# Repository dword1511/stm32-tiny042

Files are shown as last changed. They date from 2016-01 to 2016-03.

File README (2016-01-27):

This project contains a minimalist USB board for STM32F042F6P6. It has PA0-PA7
pins broken out and a LED connected to PA14, and can serve as a highly compact
development board.

My version of the board uses a LP5907 LDO. Other LDOs in SOT23-5 packages
should also work, but you may need to cut the "bypass" pin of your LDO. (LP5907
does not have a bypass pin, so it is grounded.)

The project also contains a blinky example, which may be used as a foundation
for other projects. To build, simply type "make", or read the header of the
Makefile for details. To flash, connect BOOT0 ("BT0") to 3.3V ("3V3") on the
board, plug the board into a USB slot, then type "make flash". Depending system
configuration, you may need to use sudo. See

  http://www.libopencm3.org/wiki/USB_DFU

for details. Having a udev rule in place is highly recommended so you do not
have to run make with root privilege.

Order link on OSH Park:

  https://oshpark.com/shared_projects/WYQE2OGu

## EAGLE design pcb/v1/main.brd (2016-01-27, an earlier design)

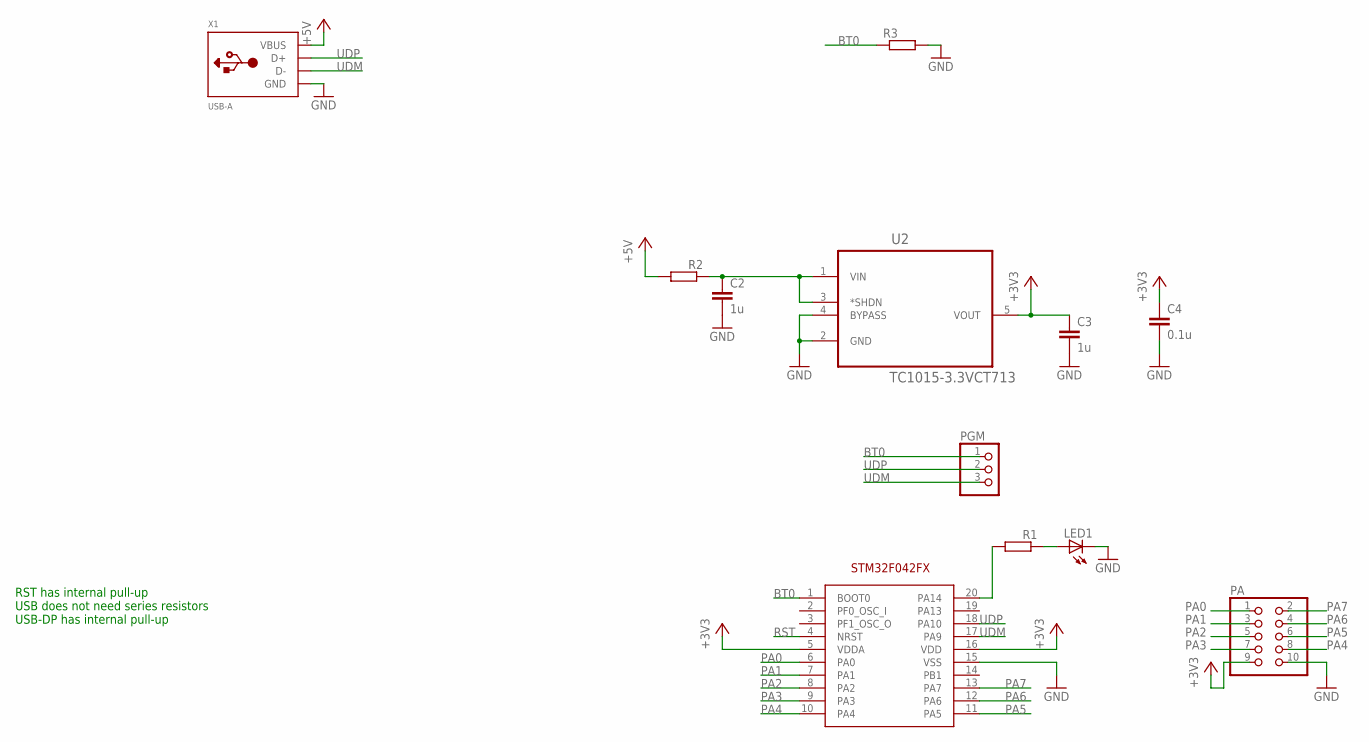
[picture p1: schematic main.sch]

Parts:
C2, C3: 1u; C0805K
C4: 0.1u; C0805K
LED1: LEDCHIPLED_0805; CHIPLED_0805
PA: PINHD-2X5; 2X05
PGM: PINHD-1X3; 1X03
R1, R2, R3: R-EU_R0805; R0805
U1: STM32F042FX; TSSOP20
U2: TC1015-3.3VCT713; SOT95P270X145-5N
X1: USB-A; MOLEX_480371000

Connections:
+3V3: C3.1, C4.1, PA.9, U1.5 (VDDA), U1.16 (VDD), U2.5 (VOUT)
+5V: R2.2, X1.1 (VBUS)
BT0: PGM.1, R3.1, U1.1 (BOOT0)
GND: C2.2, C3.2, C4.2, LED1.C, PA.10, R3.2, U1.15 (VSS), U2.2 (GND), U2.4 (BYPASS), X1.4 (GND)
unnamed: R1.2, U1.20 (PA14)
unnamed: LED1.A, R1.1
unnamed: C2.1, R2.1, U2.1 (VIN), U2.3 (*SHDN)
PA0: PA.1, U1.6 (PA0)
PA1: PA.3, U1.7 (PA1)
PA2: PA.5, U1.8 (PA2)
PA3: PA.7, U1.9 (PA3)
PA4: PA.8, U1.10 (PA4)
PA5: PA.6, U1.11 (PA5)
PA6: PA.4, U1.12 (PA6)
PA7: PA.2, U1.13 (PA7)
RST: U1.4 (NRST)
UDM: PGM.3, U1.17 (PA9), X1.2 (D-)
UDP: PGM.2, U1.18 (PA10), X1.3 (D+)

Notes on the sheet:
RST has internal pull-up USB does not need series resistors USB-DP has internal pull-up

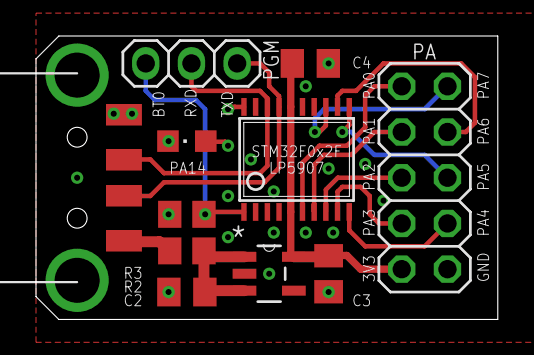
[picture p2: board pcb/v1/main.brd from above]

Board: 2 copper layers, 25.7 x 15.7 mm, 12 parts (1 on the bottom side), 17 nets.

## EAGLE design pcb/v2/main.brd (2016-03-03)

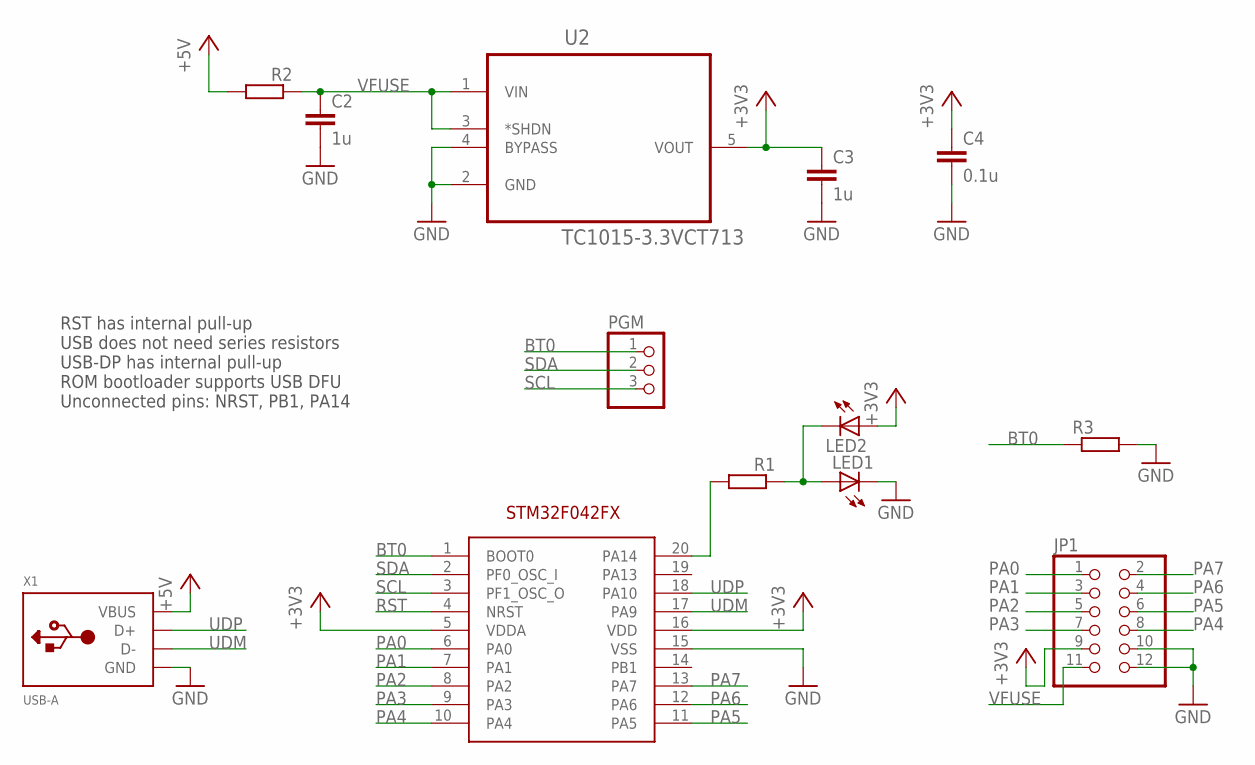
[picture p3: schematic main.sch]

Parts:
C2, C3: 1u; C0805K
C4: 0.1u; C0805K
JP1: PINHD-2X6; 2X06
LED1, LED2: LEDCHIPLED_0805; CHIPLED_0805
PGM: PINHD-1X3; 1X03
R1, R2, R3: R-EU_R0805; R0805
U1: STM32F042FX; TSSOP20
U2: TC1015-3.3VCT713; SOT95P270X145-5N
X1: USB-A; MOLEX_480371000

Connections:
+3V3: C3.1, C4.1, JP1.9, LED2.A, U1.5 (VDDA), U1.16 (VDD), U2.5 (VOUT)
+5V: R2.2, X1.1 (VBUS)
BT0: PGM.1, R3.1, U1.1 (BOOT0)
GND: C2.2, C3.2, C4.2, JP1.10, JP1.12, LED1.C, R3.2, U1.15 (VSS), U2.2 (GND), U2.4 (BYPASS), X1.4 (GND)
unnamed: R1.2, U1.20 (PA14)
unnamed: LED1.A, LED2.C, R1.1
PA0: JP1.1, U1.6 (PA0)
PA1: JP1.3, U1.7 (PA1)
PA2: JP1.5, U1.8 (PA2)
PA3: JP1.7, U1.9 (PA3)
PA4: JP1.8, U1.10 (PA4)
PA5: JP1.6, U1.11 (PA5)
PA6: JP1.4, U1.12 (PA6)
PA7: JP1.2, U1.13 (PA7)
RST: U1.4 (NRST)
SCL: PGM.3, U1.3 (PF1_OSC_O)
SDA: PGM.2, U1.2 (PF0_OSC_I)
UDM: U1.17 (PA9), X1.2 (D-)
UDP: U1.18 (PA10), X1.3 (D+)
VFUSE: C2.1, JP1.11, R2.1, U2.1 (VIN), U2.3 (*SHDN)

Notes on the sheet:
RST has internal pull-up USB does not need series resistors USB-DP has internal pull-up ROM bootloader supports USB DFU Unconnected pins: NRST, PB1, PA14

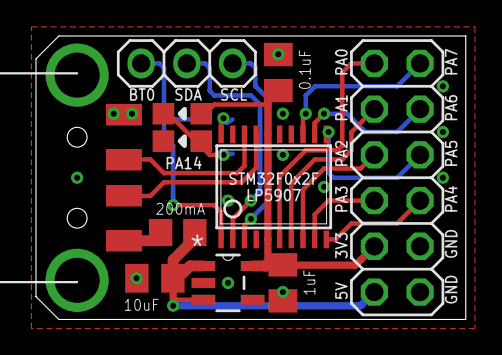
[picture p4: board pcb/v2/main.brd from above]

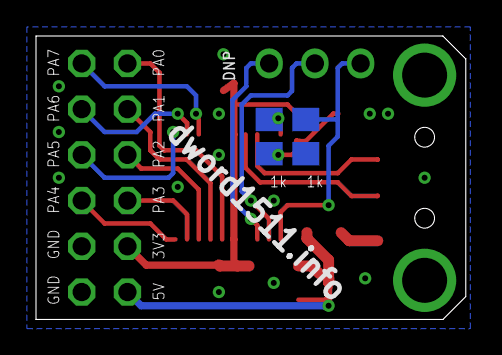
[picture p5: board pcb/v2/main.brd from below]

Board: 2 copper layers, 23.9 x 15.7 mm, 13 parts (2 on the bottom side), 19 nets.

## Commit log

2016-01-27 init commit
    [main.brd, main.sch]
2016-03-03 new version of board added
    [main.brd, main.sch]
